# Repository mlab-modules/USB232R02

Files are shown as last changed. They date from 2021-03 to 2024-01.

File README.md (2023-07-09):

# USB232R02A
The module USB232R02A is a versatile and high-quality converter from USB to serial UART with 3.3V CMOS drive output and TTL input. It features a 5V-tolerant input and utilizes the reliable FT231XQ chip from FTDI The converter uses [FT231XQ](https://ftdichip.com/products/ft231xq/) chip from FTDI, ensuring maximum compatibility with all major operating systems. With supports for Full Speed USB and Full Handshake UART signals. 

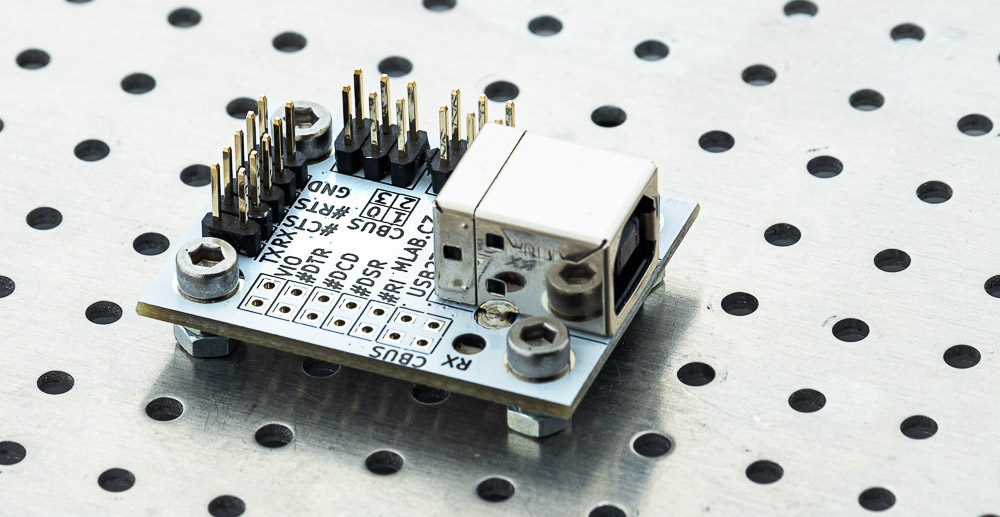
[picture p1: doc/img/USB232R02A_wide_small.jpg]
USB232R02A


The module provides the ability to power your devices via 5V from USB and 3.3V from the integrated power source simultaneously. The protection of the host device for overcurrent is realized by reversible fuse (750mA). 5V header is powerd from USB bus (trought fuse). The 3.3V power source is supplied from an LDO integrated in the FTDI converter. The 3.3V current limit is 50mA.

## What makes this module special?

USB23202A is differ from other USB-UART converters with its compatibility with MLAB standards, this fact will save any engineer or maker o lot of time. One of its key features is a unified dimension and pattern of M3 mounting screws that can be used to create a solid foundation and ground plane for your complex designs, thanks to its aluminum mounting board ALBASEx. This not only ensures mechanical durability but also makes it easy to mount your device into your final designs. With uniform cable wiring methods, this device protects your design from unnecessary malfunctions, providing you with a tool to easily and quickly prototype your high-quality devices. Invest in the USB23202A and take your designs to the next level!

## Parameters

| Parameter | Value | Description |
|---|---|---|
| Dimensions | 40,132 x 29,972 mm | PCB dimensions |
| IO | FT231XQ | Original FTDI | 
| Number of UART channels | 1 | Including all control signals | 
| USB speed | Full Speed (12 Mbps) | |
| USB connector | USB-B | USB 2.0 |
| Communication indication | 2x LED UART RX/TX | Purpose of LEDs can be changed |
| USB Class | FTDI driver | Virtual COM port |
| Power source | 5V and 3.3V (50mA) | 3.3V is provided by FT231XQ |

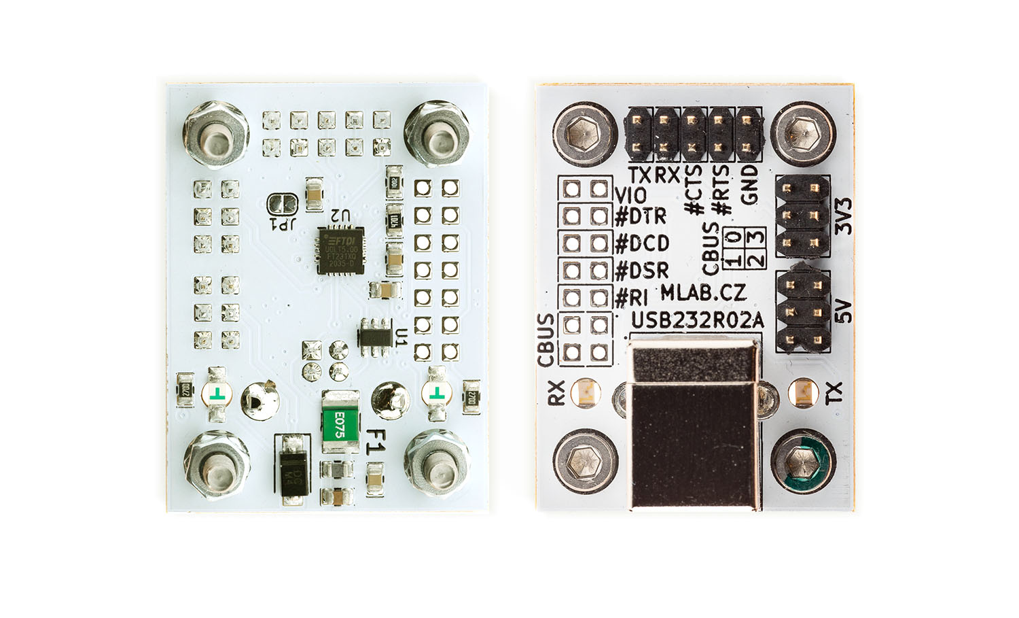
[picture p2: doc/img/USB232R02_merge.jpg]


## How to get this device? 

This device is sold by [Universal Scientific Technologies s.r.o.](https://www.ust.cz). If you are interested in our equipment, do not be afraid to [contact us](mailto:sale@ust.cz).

## Schematics

Schematics

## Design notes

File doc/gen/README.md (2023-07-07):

# PCB

Board size: 40.13x29.97 mm (1.58x1.18 inches)

- This is the size of the rectangle that contains the board
- Thickness: 1.6 mm (63 mils)
- Material: FR4
- Finish: None
- Layers: 2
- Copper thickness: 35 µm

Solder mask: TOP / BOTTOM

- Color: White

Silk screen: TOP / BOTTOM

- Color: Black

Stackup:

| Name | Type | Color | Thickness | Material | Epsilon_r | Loss tangent |
|---|---|---|---|---|---|---|
| F.SilkS | Top Silk Screen | Black | | | | |
| F.Paste | Top Solder Paste | | | | | |
| F.Mask | Top Solder Mask | White | 10 | | | |
| F.Cu | copper | | 35 | | | |
| dielectric 1 | core | | 1510 | FR4 | 4.5 | 0.020 |
| B.Cu | copper | | 35 | | | |
| B.Mask | Bottom Solder Mask | White | 10 | | | |
| B.Paste | Bottom Solder Paste  | | | | | |
| B.SilkS | Bottom Silk Screen | Black | | | | |

# Important sizes

Clearance: 0.2 mm (8 mils)

Track width: 0.2 mm (8 mils)

- By design rules: 0.2 mm (8 mils)

Drill: 0.5 mm (20 mils)

- Vias: 0.5 mm (20 mils) [Design: 0.4 mm (16 mils)]
- Pads: 1.0 mm (39 mils)
- The above values are real drill sizes, they add 0.1 mm (4 mils) to plated holes (PTH)

Via: 0.8/0.4 mm (31/16 mils)

- By design rules: 0.4/0.3 mm (16/12 mils)
- Micro via: yes [0.2/0.1 mm (8/4 mils)]
- Buried/blind via: yes
- Total: 35 (thru: 35 buried/blind: 0 micro: 0)

Outer Annular Ring: 0.15 mm (6 mils)

- By design rules: 0.26 mm (10 mils)

Eurocircuits class: 4B
- Using min drill 0.5 mm for an OAR of 0.15 mm

# General stats

Components count: (SMD/THT)

- Top: 0/9 (THT)
- Bottom: 18/0 (SMD)

Defined tracks:

Used tracks:

- 0.2 mm (8 mils) (2) defined: no
- 0.25 mm (10 mils) (152) defined: no
- 0.3 mm (12 mils) (5) defined: no
- 0.4 mm (16 mils) (41) defined: no
- 0.6 mm (24 mils) (19) defined: no

Defined vias:

Used vias:

- 0.8/0.4 mm (31/16 mils) (Count: 35, Aspect: 2.0 A) defined: no

Holes (excluding vias):

- 0.89 mm (35 mils) (36)
- 0.92 mm (36 mils) (4)
- 2.33 mm (92 mils) (2)
- 3.0 mm (118 mils) (4)

Oval holes:

Drill tools (including vias and computing adjusts and rounding):

- 0.5 mm (20 mils) (35)
- 1.0 mm (39 mils) (40)
- 2.45 mm (96 mils) (2)
- 3.1 mm (122 mils) (4)

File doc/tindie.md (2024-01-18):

#### What is it?

USB232R02 is a USB-UART adapter based on the FTDI chip [FT231XQ](https://ftdichip.com/products/ft231xq/).
The converter is characterized by its mechanical arrangement, which is compatible with the MLAB construction kit,
ensuring the robustness of manufactured devices and a unified approach to connecting individual components
using pin headers. The converter is equipped with a USB-B connector for connection to a computer, for example.
This ensures a high-quality USB connection without communication dropout. The converter supports
USB Full speed with a transfer rate of up to 12 Mbps.

USB232R02A_wide_small

The module contains a pair of output power connectors/pin headers with voltages of 5V and 3.3V.
The 5V supply is protected by a 750 mA fuse and is obtained from USB voltage. The 3.3V comes from an internal 
LDO with a maximum load of 50mA. The module is equipped with a pair of LEDs indicating RX/TX communication over USB.

The FTDI chip has a CMOS output (3.3V levels), and the pins are 5V compatible.
As a result, the module can be connected to both 3.3V and 5V constructions without configuration
changes and without the risk of damaging them.

The module includes all control pins (Handshake). Output signals are routed to pin headers with a standard 2.54mm pitch, and all pins are doubled. This way, you can easily create extensive constructions without dealing with complex connections or split connection cables.

The module has a wide range of uses. It can be used to connect various microcontrollers
to a computer for data capturing or for controlling them. It can also be used for configuring
or powering many existing devices that are often equipped with a serial interface at UART levels.
With the right cable, this converter can be used as a configuration interface for some networking devices,
for example.

You can find additional device parameters in the [README of the converter](https://github.com/mlab-modules/USB232R02#readme).

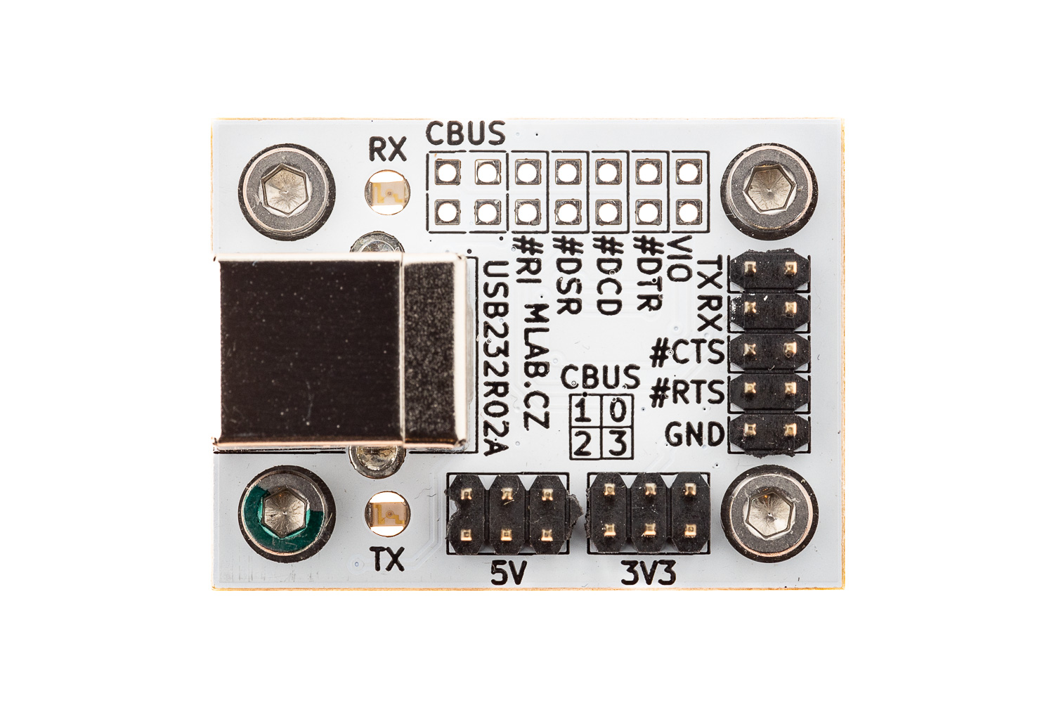
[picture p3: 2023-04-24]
doc/img/USB232R02_1.jpg

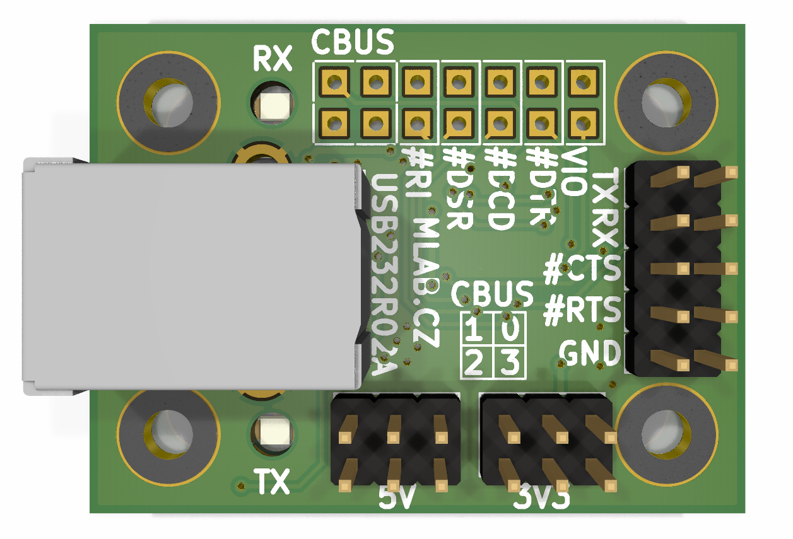
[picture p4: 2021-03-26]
doc/img/USB232R02A_top.png

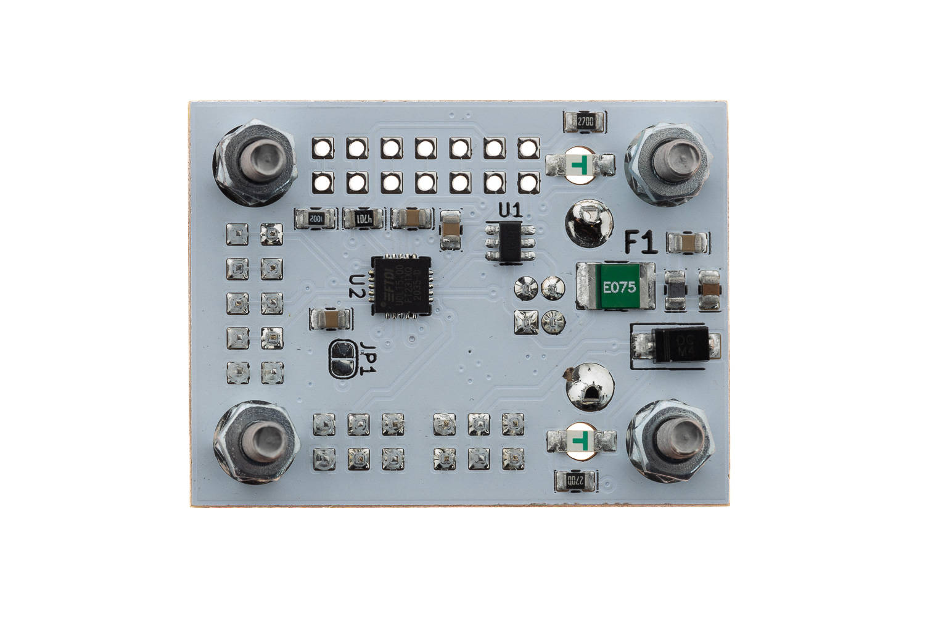
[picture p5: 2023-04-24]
doc/img/USB232R02_2.jpg

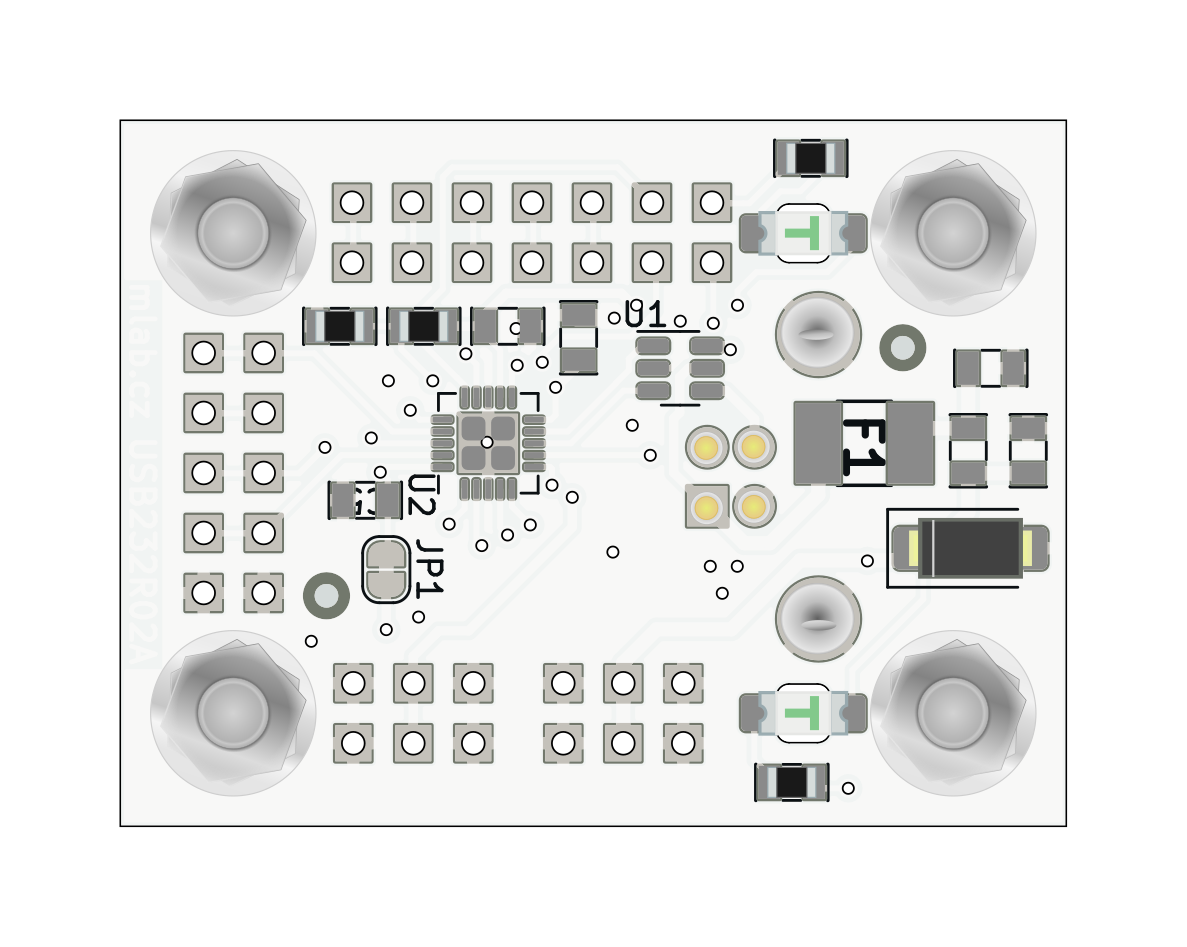
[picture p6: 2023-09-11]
doc/gen/img/USB232R02-bottom.png

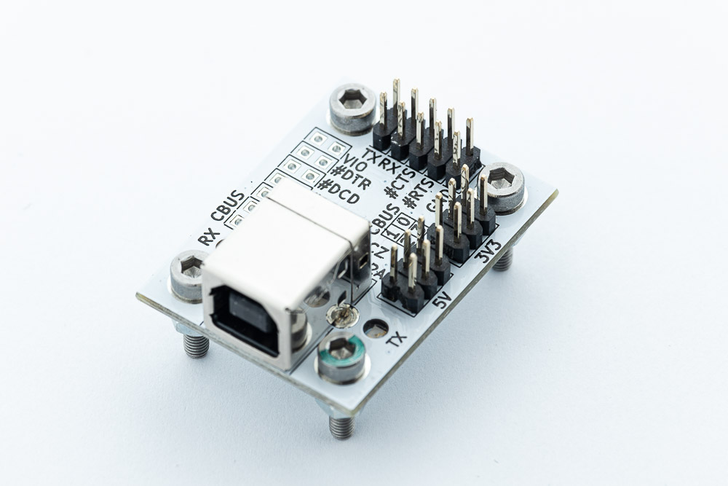
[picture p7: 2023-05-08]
doc/img/USB232R02A3.jpg

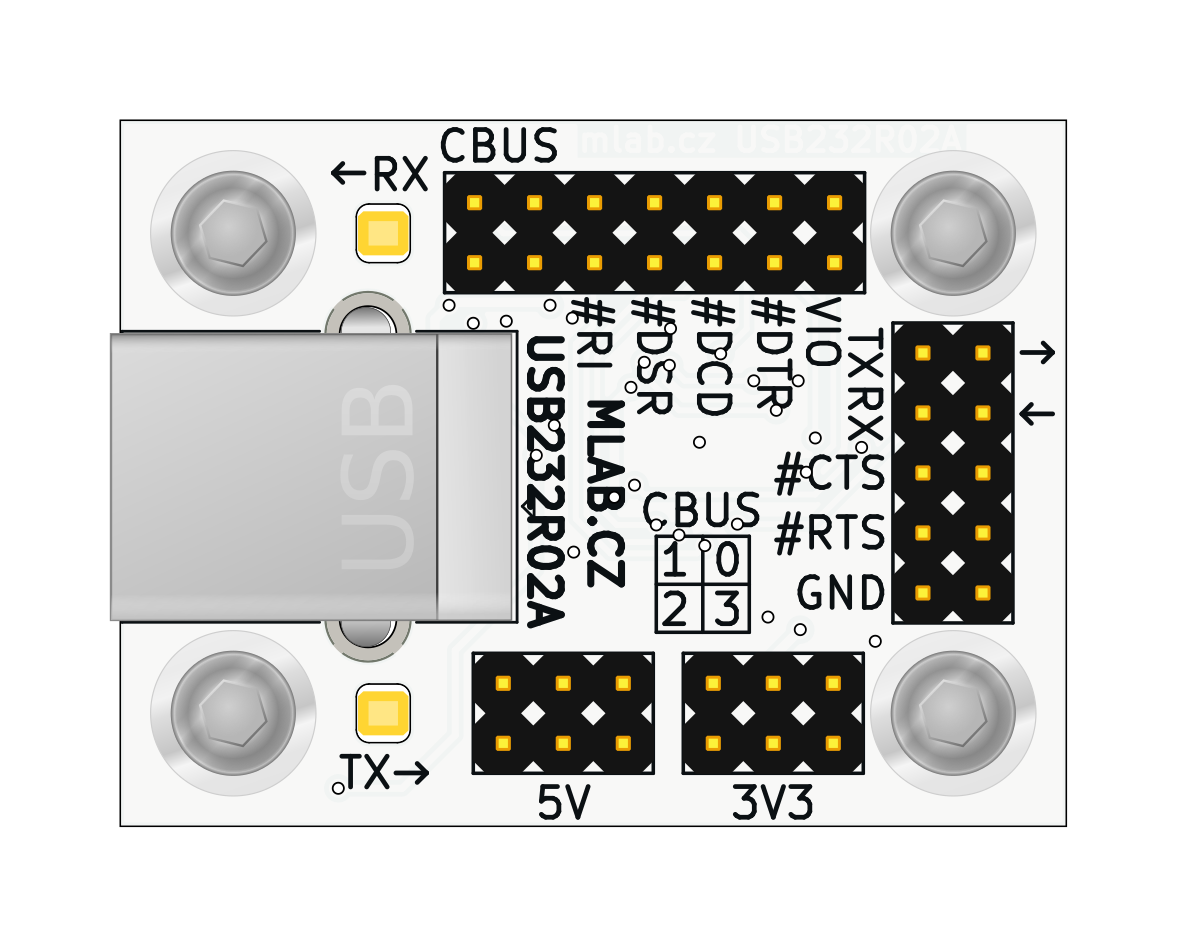
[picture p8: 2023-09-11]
doc/gen/img/USB232R02-top.png

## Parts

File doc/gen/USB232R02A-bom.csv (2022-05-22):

Row | Description | Part | References | Value | Footprint | Quantity Per PCB | Status | Datasheet | UST_ID
1 | Unpolarized capacitor | C | C1 | 10nF | SMD-0805 | 1 |  | ~ | 5c70984712875079b91f8b49
2 | Unpolarized capacitor | C | C3 C4 C5 | 100nF | SMD-0805 | 3 |  | ~ | 5c70984712875079b91f8b4c
3 | Unpolarized capacitor | C | C2 | 10uF | SMD-0805 | 1 |  | ~ | 5c70984812875079b91f8bbd
4 | Light emitting diode | LED | D3 | GREEN | LED_1206 | 1 |  | ~ | 5c70984412875079b91f8895
5 | Diode | D | D1 | M4 | D_SMA | 1 |  | ~ | 5c70984512875079b91f88ac
6 | Light emitting diode | LED | D2 | RED | LED_1206 | 1 |  | ~ | 5c70984412875079b91f8896
7 | Resettable fuse, polymeric positive temperature coefficient | Polyfuse | F1 | 750mA | 1812 | 1 |  | ~ | 5c70984512875079b91f88d2
8 | Ferrite bead, small symbol | FerriteBead_Small | FB1 | BLM21PG300SN1D | SMD-0805 | 1 |  | ~ | 5c70984412875079b91f87fd
9 | 2x01 2.54 mm pitch header, 2 pins next to each other are connected | HEADER_2x01_PARALLEL | J4 J9 J10 J11 J12 | - | Straight_2x01 | 5
10 | 1x01 2.54 mm pitch header | HEADER_1x01 | J13 J14 J15 J16 | - | Straight_1x01 | 4
11 | 2x01 2.54 mm pitch header, 2 pins next to each other are connected | HEADER_2x01_PARALLEL | J5 J6 J7 J8 J17 | HEADER_2x01_PARALLEL | Straight_2x01 | 5
12 | 2x03 2.54 mm pitch header, 2 pins next to each other are connected | HEADER_2x03_PARALLEL | J2 J3 | HEADER_2x03_PARALLEL | Straight_2x03 | 2
13 | USB Type B connector | USB_B | J1 | USB_B | USB_B_OST_USB-B1HSxx_Horizontal | 1 |  | ~ | 5c70984412875079b91f87a8
14 | Resistor | R | R3 R4 | 270R | SMD-0805 | 2 |  | ~ | 5c70984512875079b91f8983
15 | Resistor | R | R1 | 4k7 | SMD-0805 | 1 |  | ~ | 5c70984612875079b91f8995
16 | Resistor | R | R2 | 10k | SMD-0805 | 1 |  | ~ | 5c70984612875079b91f899f
17 | Full Speed USB to Full Handshake UART, QFN-20 | FT231XQ | U2 | FT231XQ | QFN-20-1EP_4x4mm_P0.5mm_EP2.5x2.5mm | 1 |  | https://www.ftdichip.com/Support/Documents/DataSheets/ICs/DS_FT231X.pdf | 605d7fe0128750769e769adb
18 | Very low capacitance ESD protection diode, 2 data-line, SOT-23-6 | USBLC6-2SC6 | U1 | USBLC6-2SC6 | SOT-23-6 | 1 |  | https://www.st.com/resource/en/datasheet/usblc6-2.pdf | 5e82e0691287502a334a778c
Project info:
Schematic: | USB232R02A
Variant: | default
Revision:
Date: | 2021-03-25
KiCad Version: | 6.0.4-6f826c9f35~116~ubuntu20.04.1
Statistics:
Component Groups: | 18
Component Count: | 33
Fitted Components: | 33
Number of PCBs: | 1
Total Components: | 33

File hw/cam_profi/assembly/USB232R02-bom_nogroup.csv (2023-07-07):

Component | Description | Part | References | Value | Footprint | Quantity Per PCB | Datasheet | lcsc | ust_id
1 | Unpolarized capacitor | C | C1 | 10nF | SMD-0805 | 1 | ~ | C472806 | 5c70984712875079b91f8b49
2 | Unpolarized capacitor | C | C3C4C5 | 100nF | SMD-0805 | 3 | ~ | C111492 | 5c70984712875079b91f8b4c
3 | Unpolarized capacitor | C | C2 | 10uF | SMD-0805 | 1 | ~ | C17024 | 5c70984812875079b91f8bbd
4 | Light emitting diode | LED | D3 | GREEN | LED_1206_2 | 1 | https://www.tme.eu/Document/283cf8402cc8d70fa16840405395cb5a/kptr-3216cgck.pdf | C598394 | 5c70984412875079b91f8895
5 | Diode | D | D1 | M4 | D_SMA | 1 | ~ | C466506 | 5c70984512875079b91f88ac
6 | Light emitting diode | LED | D2 | RED | LED_1206_2 | 1 | http://www.kingbright.com/attachments/file/psearch/000/00/20160808bak/KPTR-3216SURCK(Ver.15A).pdf | C598398 | 5c70984412875079b91f8896
7 | Resettable fuse, polymeric positive temperature coefficient | Polyfuse | F1 | 750mA | 1812 | 1 | ~ | C269130 | 5c70984512875079b91f88d2
8 | Ferrite bead, small symbol | FerriteBead_Small | FB1 | BLM21PG300SN1D | SMD-0805 | 1 | ~ | C16903 | 5c70984412875079b91f87fd
9 | 2x03 2.54 mm pitch header, 2 pins next to each other are connected | HEADER_2x03_PARALLEL | J2J3 | HEADER_2x03 | Straight_2x03 | 2 |  | C706893
10 | 2x05 2.54 mm pitch header, 2 pins next to each other are connected | HEADER_2x05_PARALLEL | J19 | HEADER_2x05 | Straight_2x05 | 1 |  | C706895
11 | 2x07 2.54 mm pitch header | HEADER_2x07 | J18 | HEADER_2x07 | Straight_2x07 | 1 |  | C706897
12 | USB Type B connector | USB_B | J1 | USB_B | USB_B_OST_USB-B1HSxx_Horizontal | 1 | ~ | C490687 | 5c70984412875079b91f87a8
13 | Resistor | R | R3R4 | 270R | SMD-0805 | 2 | ~ | C228675 | 5c70984512875079b91f8983
14 | Resistor | R | R1 | 4k7 | SMD-0805 | 1 | ~ | C60816 | 5c70984612875079b91f8995
15 | Resistor | R | R2 | 10k | SMD-0805 | 1 | ~ | C84376 | 5c70984612875079b91f899f
16 | Full Speed USB to Full Handshake UART, QFN-20 | FT231XQ | U2 | FT231XQ | QFN-20-1EP_4x4mm_P0.5mm_EP2.5x2.5mm | 1 | https://www.ftdichip.com/Support/Documents/DataSheets/ICs/DS_FT231X.pdf | C132159 | 605d7fe0128750769e769adb
17 | Very low capacitance ESD protection diode, 2 data-line, SOT-23-6 | USBLC6-2SC6 | U1 | USBLC6-2SC6 | SOT-23-6 | 1 | https://www.st.com/resource/en/datasheet/usblc6-2.pdf | C7519 | 5e82e0691287502a334a778c

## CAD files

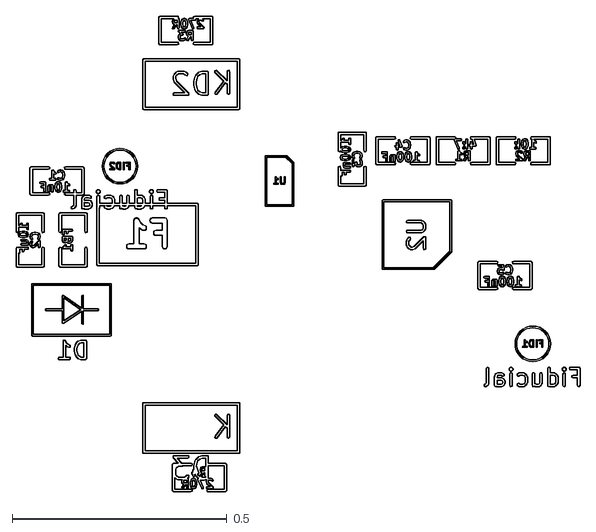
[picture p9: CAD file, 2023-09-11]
doc/gen/dxf/USB232R02-B_Fab.dxf
1.31 x 1.11

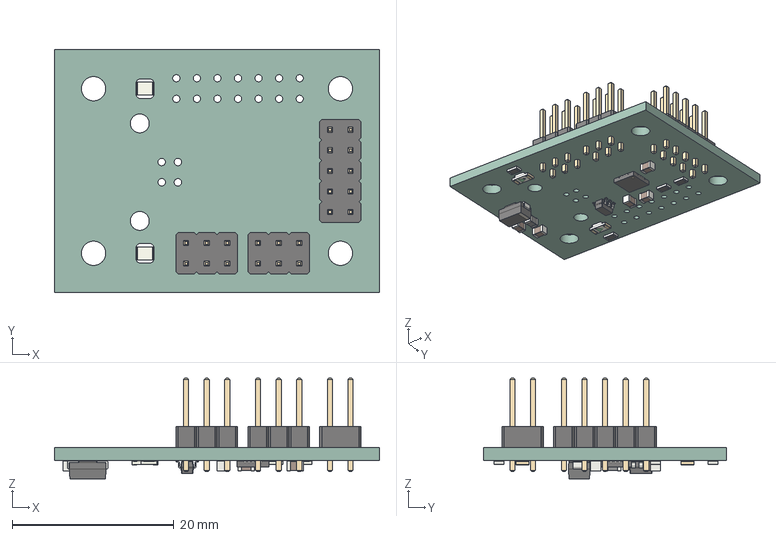
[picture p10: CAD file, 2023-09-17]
doc/gen/USB232R02.step
40.1 x 30.0 x 12.4 mm
tmpykgqynk8 PCB

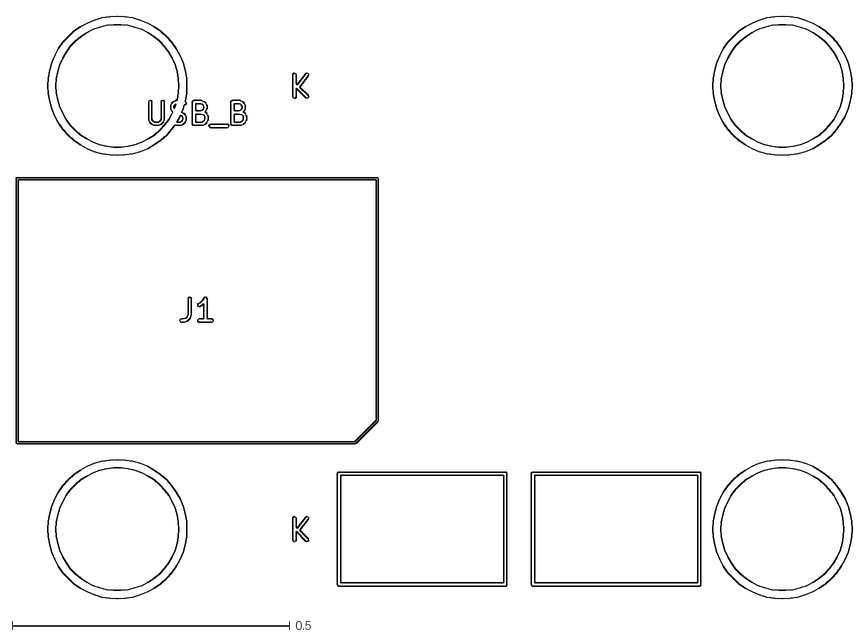
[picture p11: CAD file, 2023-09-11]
doc/gen/dxf/USB232R02-F_Fab.dxf
1.51 x 1.05

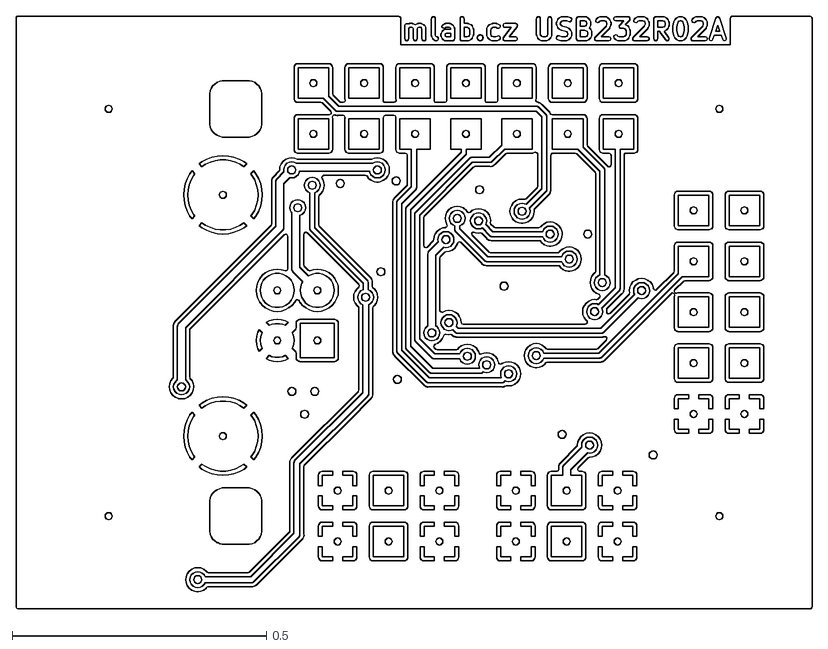
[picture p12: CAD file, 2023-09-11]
doc/gen/dxf/USB232R02-F_Cu.dxf
1.56 x 1.16

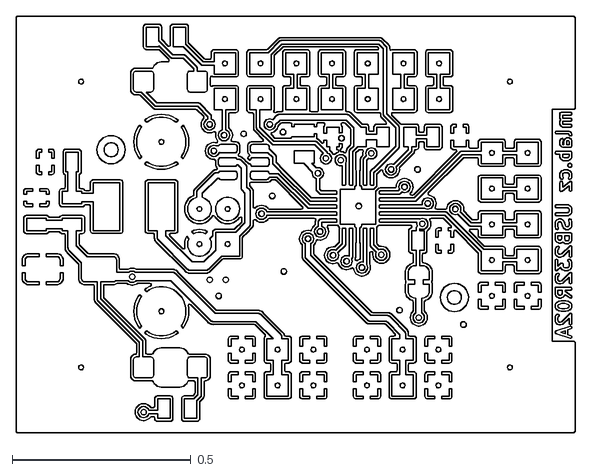
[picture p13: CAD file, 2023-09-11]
doc/gen/dxf/USB232R02-B_Cu.dxf
1.56 x 1.16

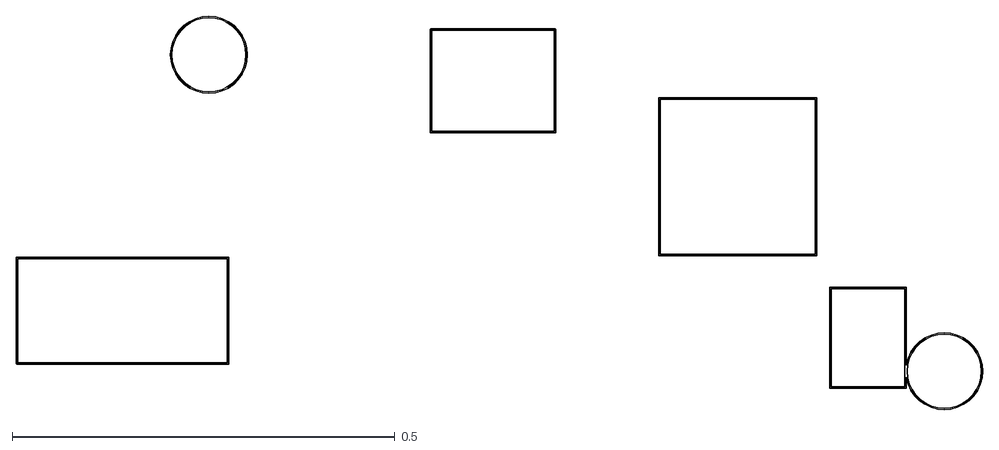
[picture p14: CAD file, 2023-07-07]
doc/gen/dxf/USB232R02-B_Courtyard.dxf
1.26 x 0.514

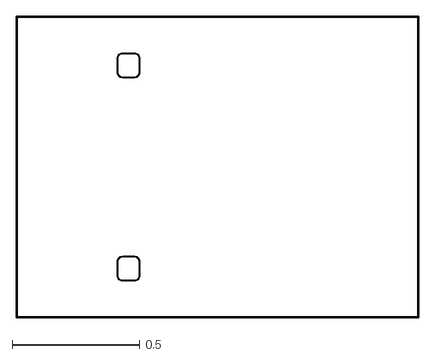
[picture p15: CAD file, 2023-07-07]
doc/gen/dxf/USB232R02-Edge_Cuts.dxf
1.58 x 1.18

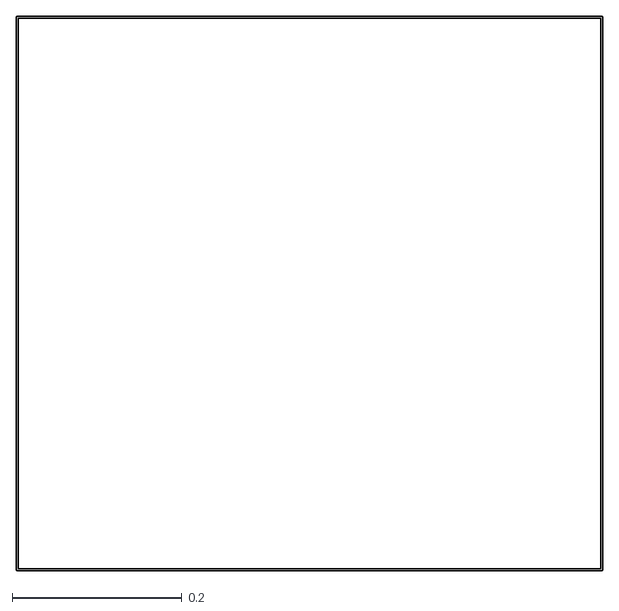
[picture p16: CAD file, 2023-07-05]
doc/gen/dxf/USB232R02-F_Courtyard.dxf
0.691 x 0.653

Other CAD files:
doc/gen/dxf/USB232R02-Uivatel_9.dxf
doc/gen/dxf/USB232R02-Uivatel_8.dxf
doc/gen/dxf/USB232R02-User_Drawings.dxf
doc/gen/dxf/USB232R02A-Uivatel_5.dxf
doc/gen/dxf/USB232R02A-Uivatel_3.dxf
doc/gen/dxf/USB232R02-Uivatel_1.dxf
doc/gen/dxf/USB232R02A-User_Drawings.dxf
doc/gen/dxf/USB232R02A-Uivatel_2.dxf
doc/gen/dxf/USB232R02-Uivatel_5.dxf
doc/gen/dxf/USB232R02-User_Eco2.dxf
doc/gen/dxf/USB232R02-B_Adhesive.dxf
doc/gen/dxf/USB232R02-B_Mask.dxf
doc/gen/dxf/USB232R02-B_Paste.dxf
doc/gen/dxf/USB232R02-B_Silkscreen.dxf
doc/gen/dxf/USB232R02-F_Adhesive.dxf
doc/gen/dxf/USB232R02-F_Mask.dxf
doc/gen/dxf/USB232R02-F_Paste.dxf
doc/gen/dxf/USB232R02-F_Silkscreen.dxf
doc/gen/dxf/USB232R02-Margin.dxf
doc/gen/dxf/USB232R02-Uivatel_2.dxf
doc/gen/dxf/USB232R02-Uivatel_3.dxf
doc/gen/dxf/USB232R02-Uivatel_4.dxf
doc/gen/dxf/USB232R02-Uivatel_6.dxf
doc/gen/dxf/USB232R02-Uivatel_7.dxf
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

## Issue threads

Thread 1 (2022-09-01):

USB signals needs to be routed differentially

kaklik, 2022-09-01:
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

Vbus should be routed in the opposite direction from pin 5 of U1. Then D- and D+ could be routed parallel with the same length.  Similar constraints apply to DM and DP signals.

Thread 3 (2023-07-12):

Missing power LED

roman-dvorak, 2023-07-12:
Na modulu není LEDka indikující přítomnost napájení. Vzhledem k tomu, že tento modul často slouží jako zdroj napájení, tak by bylo užitečné, aby takovou indikaci obsahoval.

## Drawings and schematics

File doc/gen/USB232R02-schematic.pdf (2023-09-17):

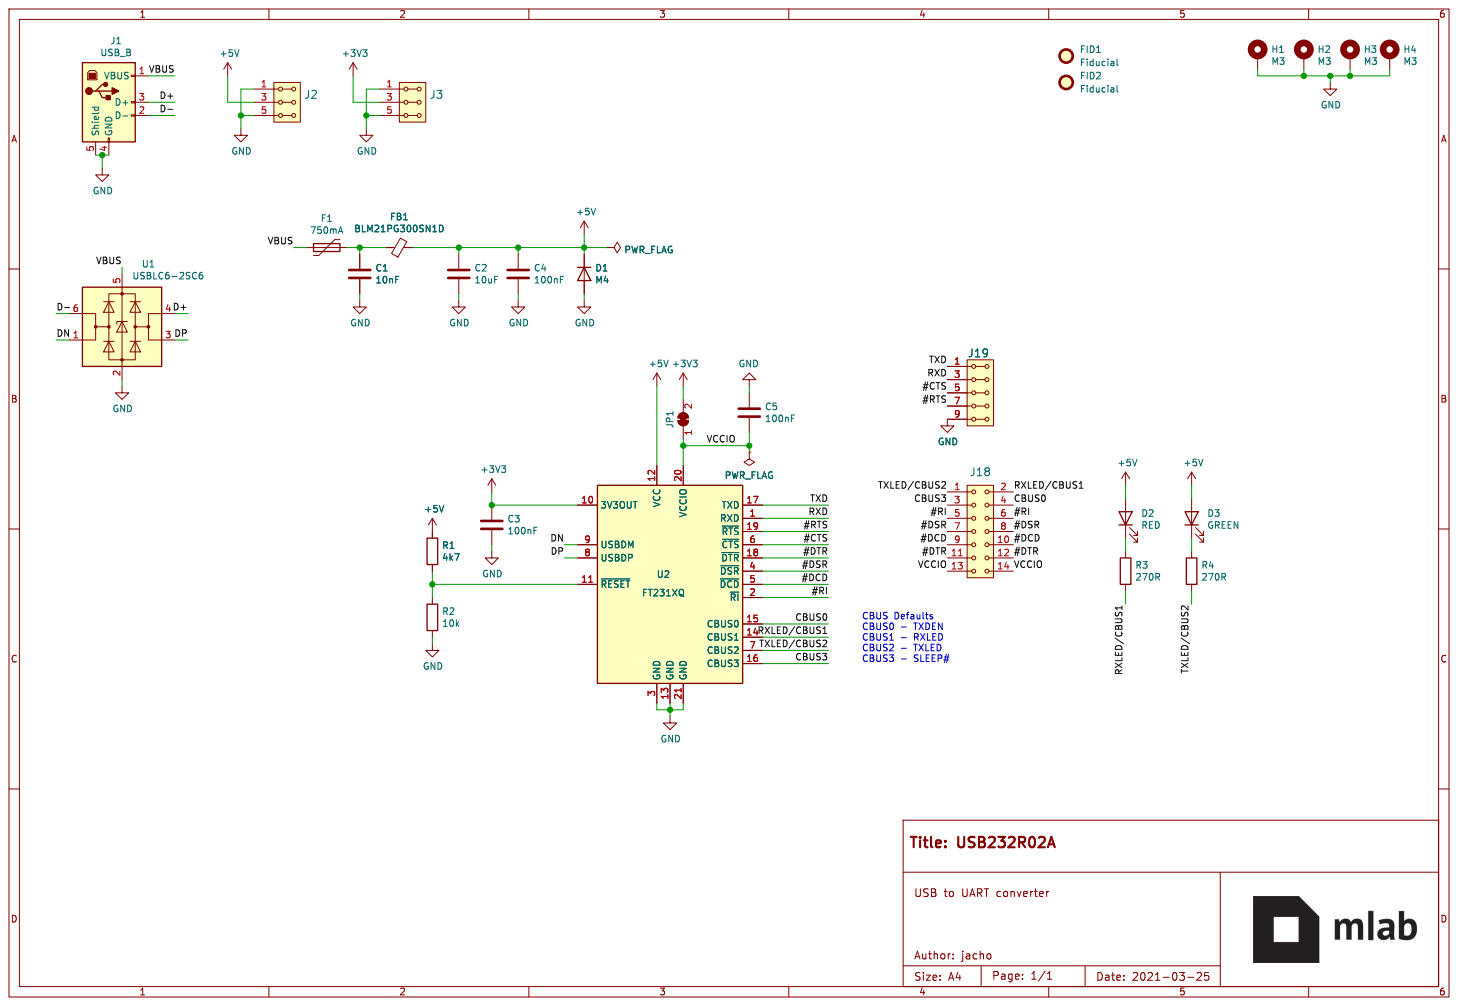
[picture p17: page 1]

3 ~{DSR}4 ~{DCD}5 ~{CTS}6 CBUS2 7 USBDP 8 USBDM 9 FB1 BLM21PG300SN1D

3 ~{DSR}4 ~{DCD}5 ~{CTS}6 CBUS2 7 USBDP 8 USBDM 9 U2 FT231XQ

USB to UART converter

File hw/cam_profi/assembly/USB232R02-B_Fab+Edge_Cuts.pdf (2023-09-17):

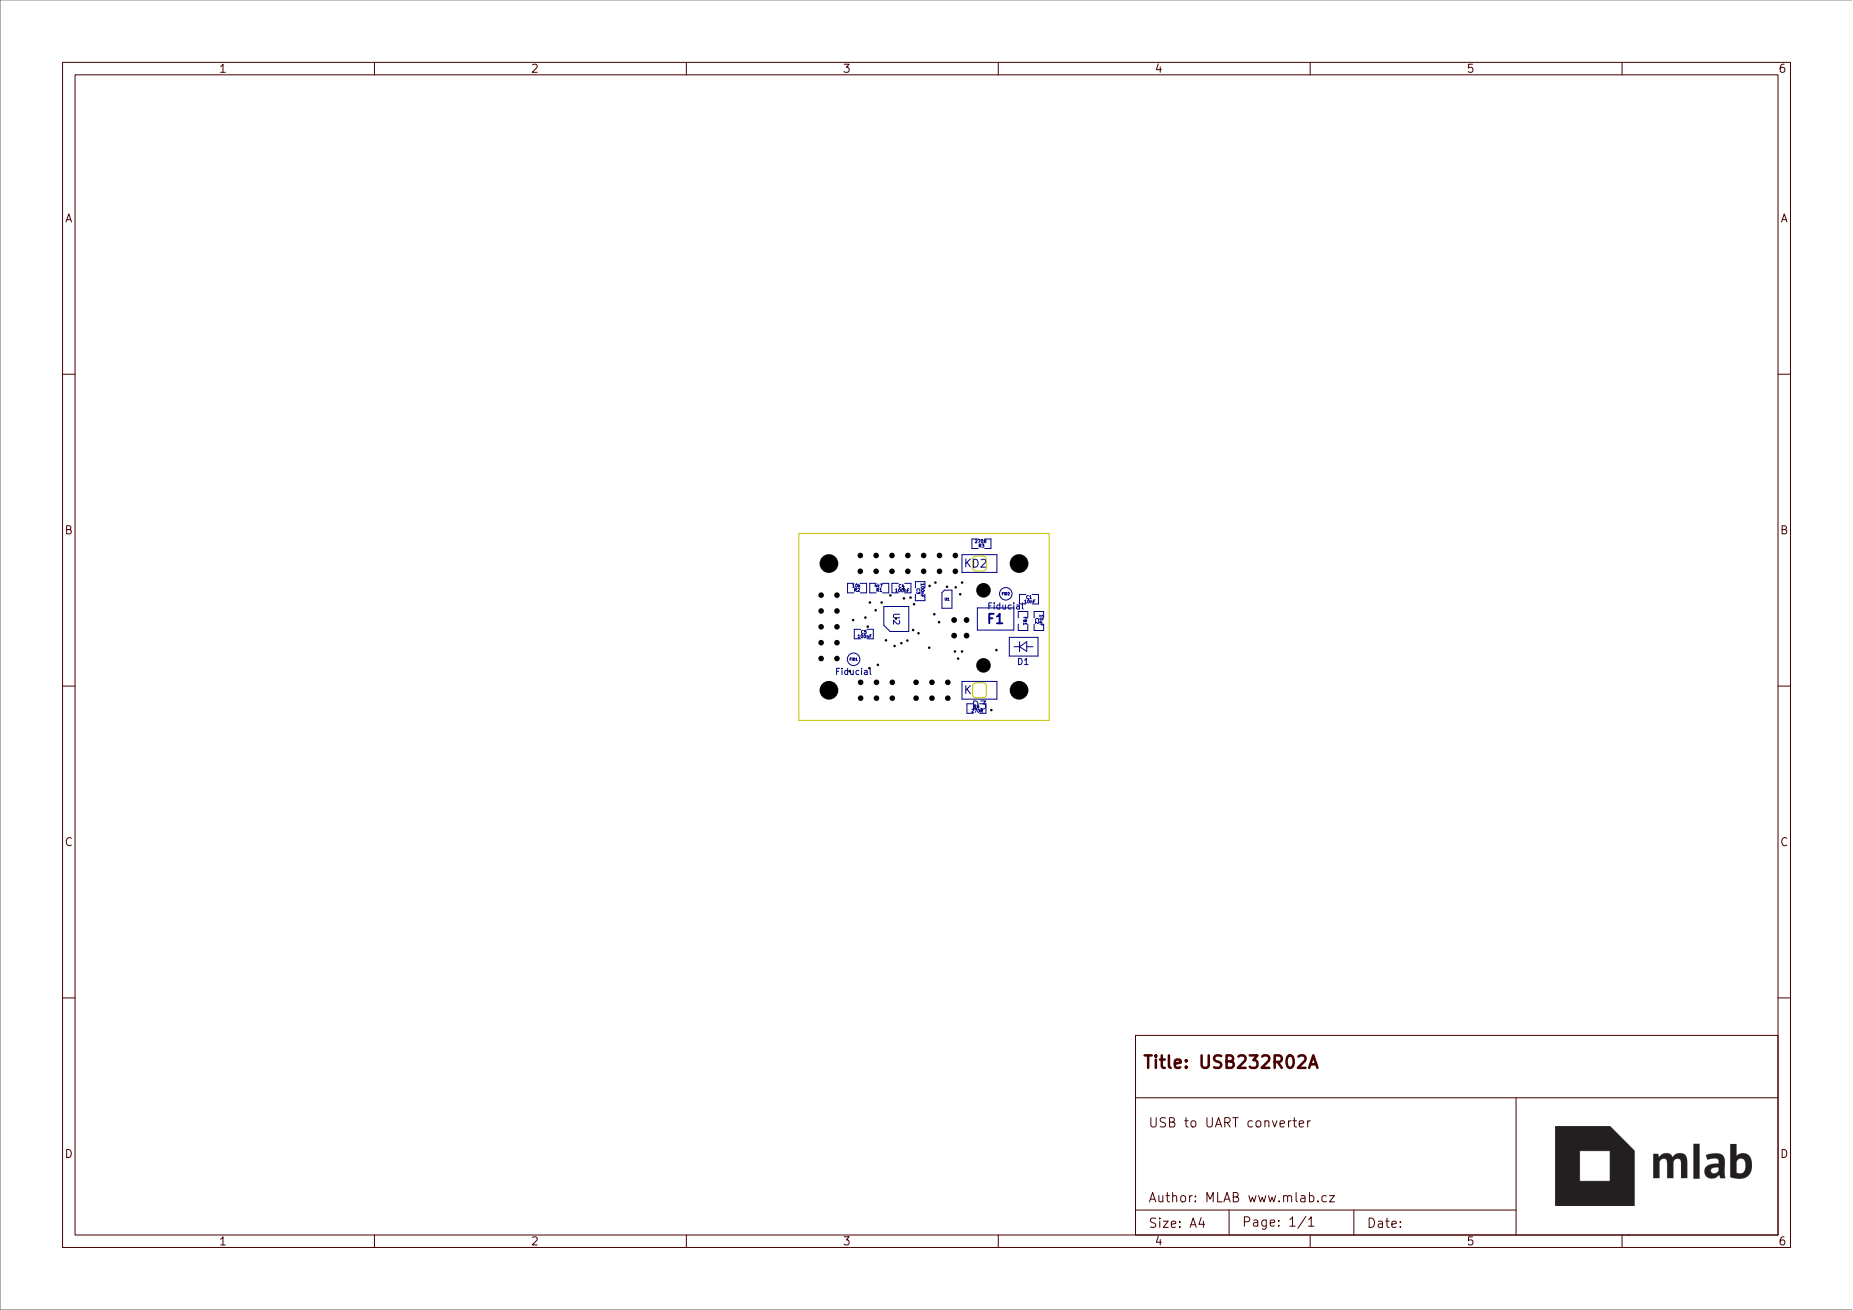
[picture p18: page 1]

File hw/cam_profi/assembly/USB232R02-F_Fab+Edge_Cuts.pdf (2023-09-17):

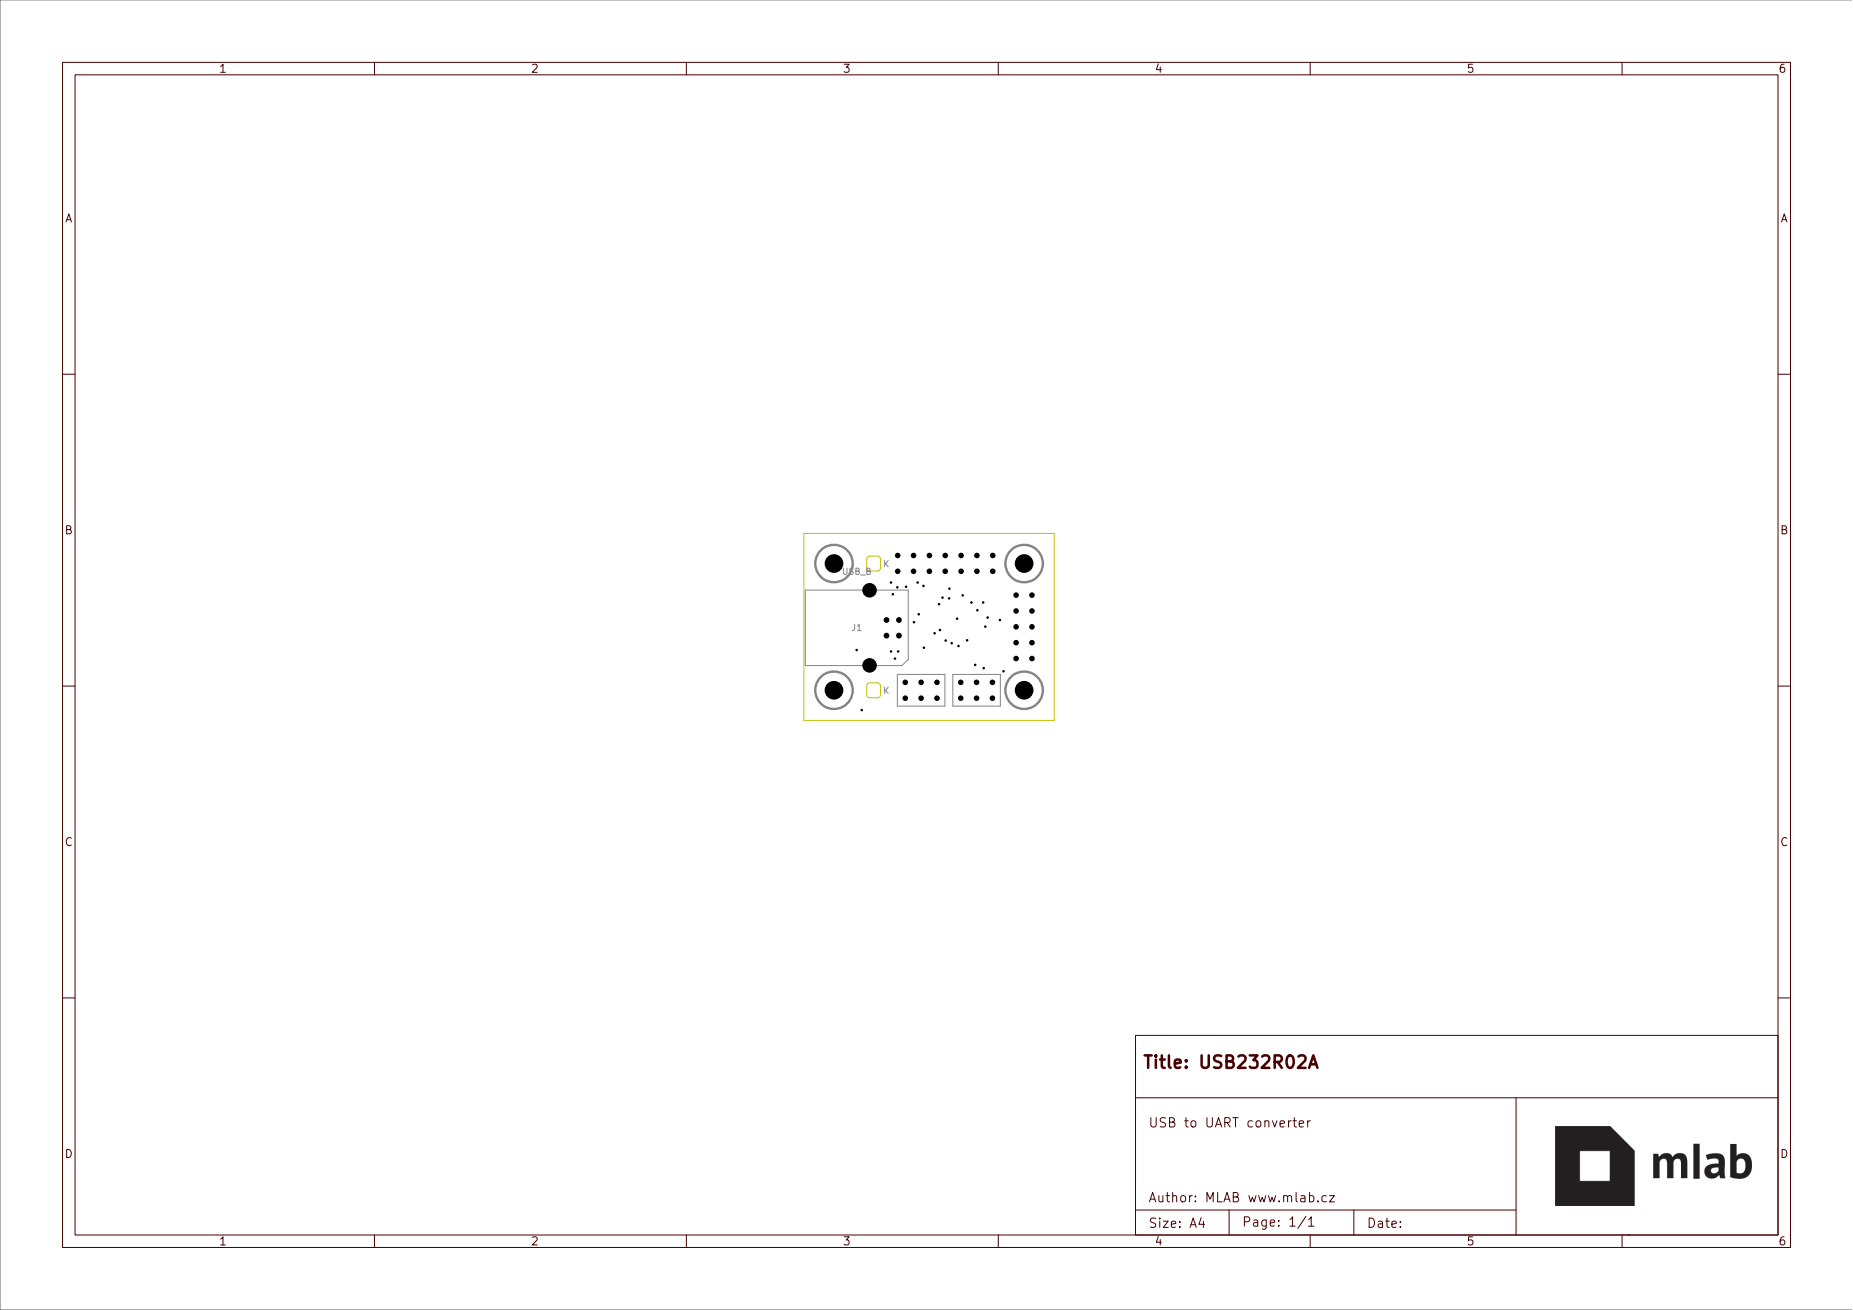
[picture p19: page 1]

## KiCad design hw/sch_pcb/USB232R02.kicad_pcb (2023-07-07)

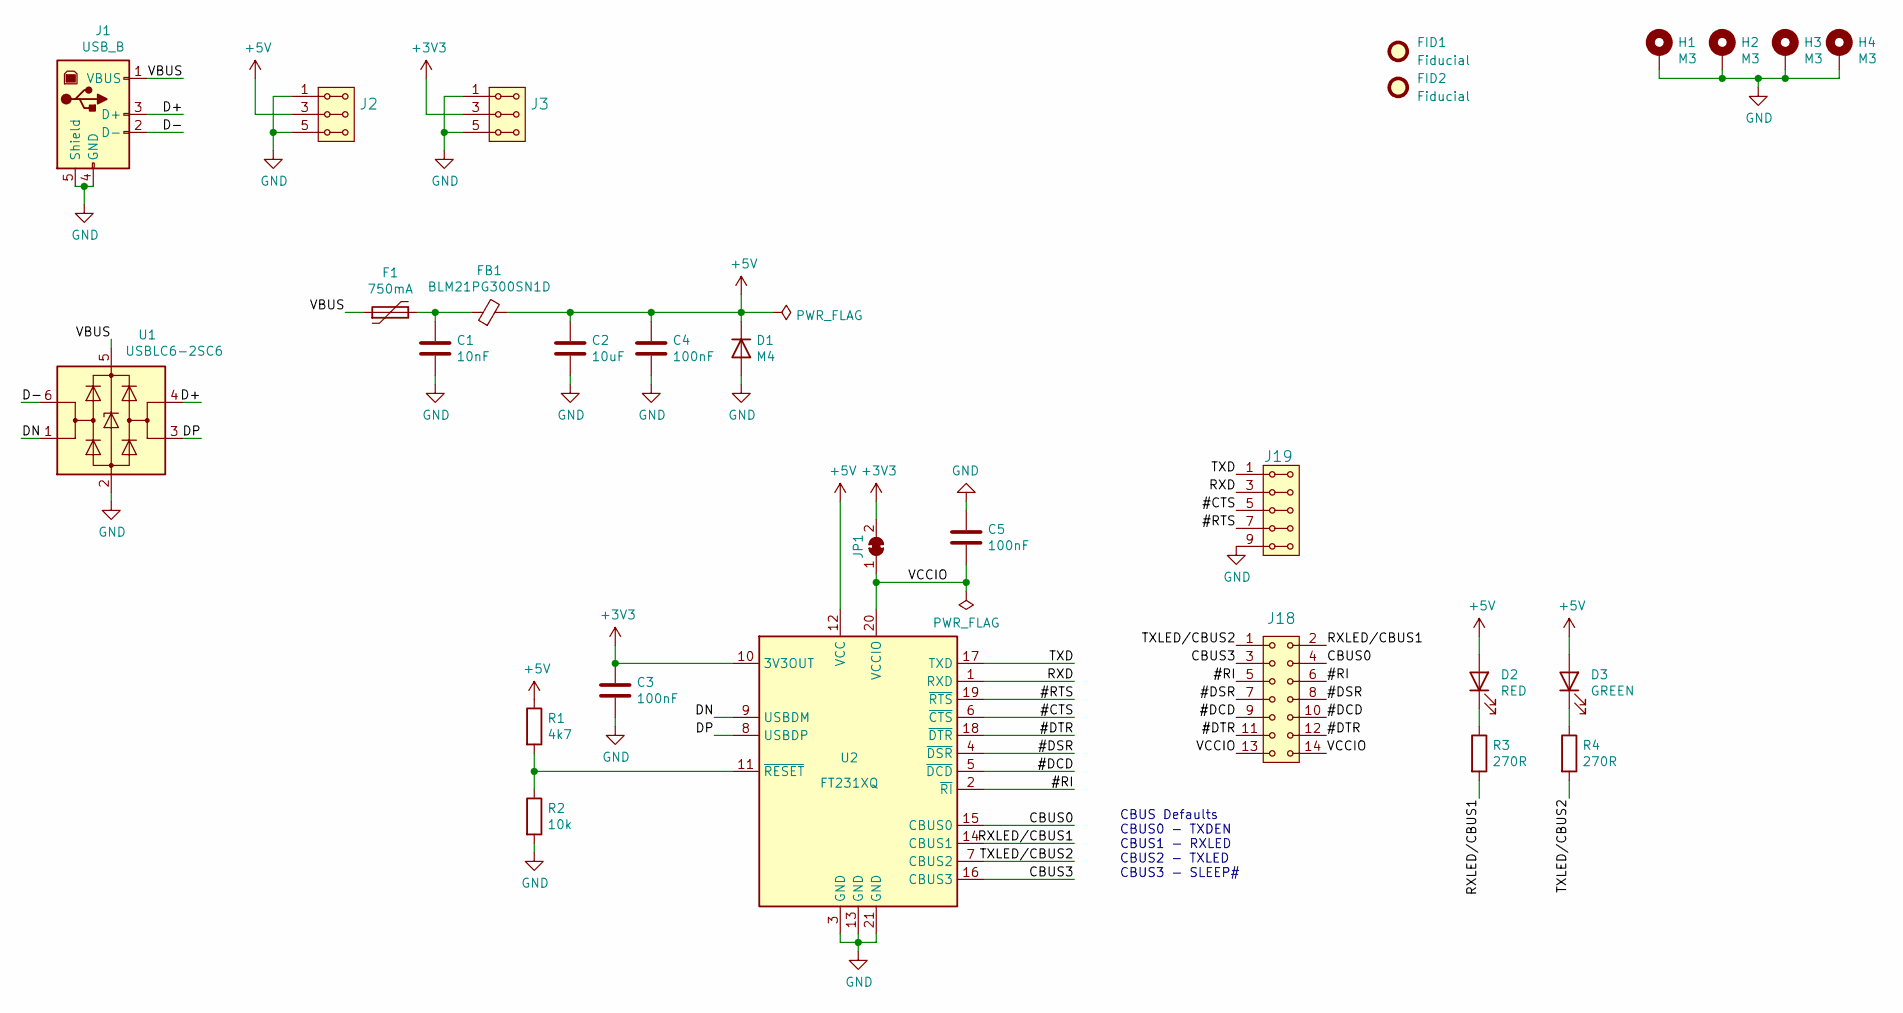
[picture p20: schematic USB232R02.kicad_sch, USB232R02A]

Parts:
C1: 10nF; SMD-0805; LCSC C913645
C2: 10uF; SMD-0805; LCSC C17024
C3, C4, C5: 100nF; SMD-0805; LCSC C111492
D1: M4; D_SMA; LCSC C466506
D2: RED; LED_1206_2; LCSC C598398
D3: GREEN; LED_1206_2; LCSC C598394
F1: 750mA; 1812; LCSC C269130
FB1: BLM21PG300SN1D; SMD-0805; LCSC C16903
FID1, FID2: Fiducial; Fiducial_1mm_Mask2mm
H1, H2, H3, H4: M3; MountingHole_3mm
J1: USB_B; USB_B_OST_USB-B1HSxx_Horizontal; LCSC C490687
J2, J3: HEADER_2x03; Straight_2x03; LCSC C706893
J18: HEADER_2x07; Straight_2x07; LCSC C706897
J19: HEADER_2x05; Straight_2x05; LCSC C706895
JP1: SolderJumper_2_Bridged; SolderJumper-2_P1.3mm_Bridged_RoundedPad1.0x1.5mm
R1: 4k7; SMD-0805; LCSC C60816
R2: 10k; SMD-0805; LCSC C84376
R3, R4: 270R; SMD-0805; LCSC C228675
U1: USBLC6-2SC6; SOT-23-6; LCSC C7519
U2: FT231XQ; QFN-20-1EP_4x4mm_P0.5mm_EP2.5x2.5mm; LCSC C132159

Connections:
+3V3: C3.1, J3.3, J3.4, JP1.2 (B), U2.10 (3V3OUT)
+5V: C2.1, C4.1, D1.1 (K), D2.2 (A), D3.2 (A), FB1.2, J2.3, J2.4, R1.1, U2.12 (VCC)
/#CTS: J19.5, J19.6, U2.6 (~CTS)
/#DCD: J18.9, J18.10, U2.5 (~DCD)
/#DSR: J18.7, J18.8, U2.4 (~DSR)
/#DTR: J18.11, J18.12, U2.18 (~DTR)
/#RI: J18.5, J18.6, U2.2 (~RI)
/#RTS: J19.7, J19.8, U2.19 (~RTS)
/CBUS0: J18.4, U2.15 (CBUS0)
/CBUS3: J18.3, U2.16 (CBUS3)
/D+: J1.3 (D+), U1.4 (I/O2)
/D-: J1.2 (D-), U1.6 (I/O1)
/DN: U1.1 (I/O1), U2.9 (USBDM)
/DP: U1.3 (I/O2), U2.8 (USBDP)
/RXD: J19.3, J19.4, U2.1 (RXD)
/RXLED/CBUS1: J18.2, R3.2, U2.14 (CBUS1)
/TXD: J19.1, J19.2, U2.17 (TXD)
/TXLED/CBUS2: J18.1, R4.2, U2.7 (CBUS2)
/VBUS: F1.1, J1.1 (VBUS), U1.5 (VBUS)
/VCCIO: C5.2, J18.13, J18.14, JP1.1 (A), U2.20 (VCCIO)
GND: C1.2, C2.2, C3.2, C4.2, C5.1, D1.2 (A), H1.1, H2.1, H3.1, H4.1, J1.4 (GND), J1.5 (Shield), J2.1, J2.2, J2.5, J2.6, J3.1, J3.2, J3.5, J3.6, J19.9, J19.10, R2.2, U1.2 (GND), U2.3 (GND), U2.13 (GND), U2.21 (GND)
unnamed: C1.1, F1.2, FB1.1
unnamed: D2.1 (K), R3.1
unnamed: D3.1 (K), R4.1
unnamed: R1.2, R2.1, U2.11 (~RESET)

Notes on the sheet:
CBUS Defaults CBUS0 - TXDEN CBUS1 - RXLED CBUS2 - TXLED CBUS3 - SLEEP#

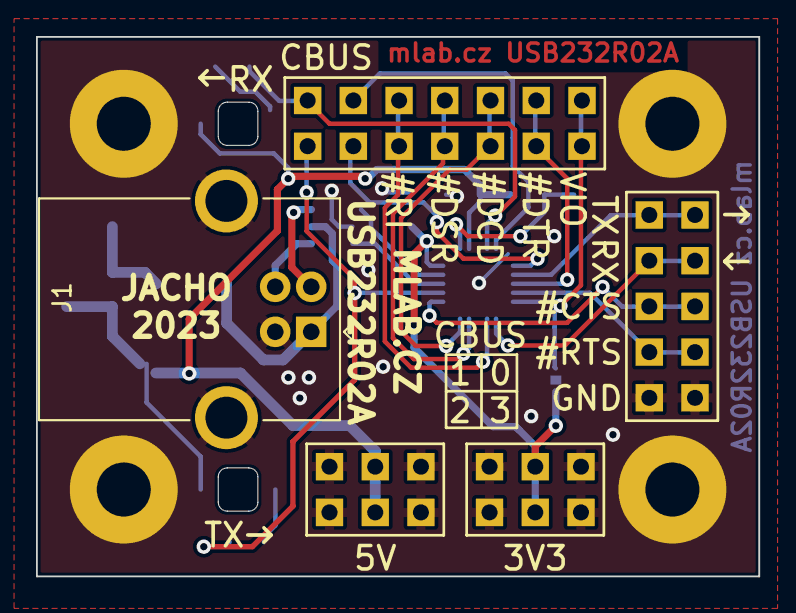
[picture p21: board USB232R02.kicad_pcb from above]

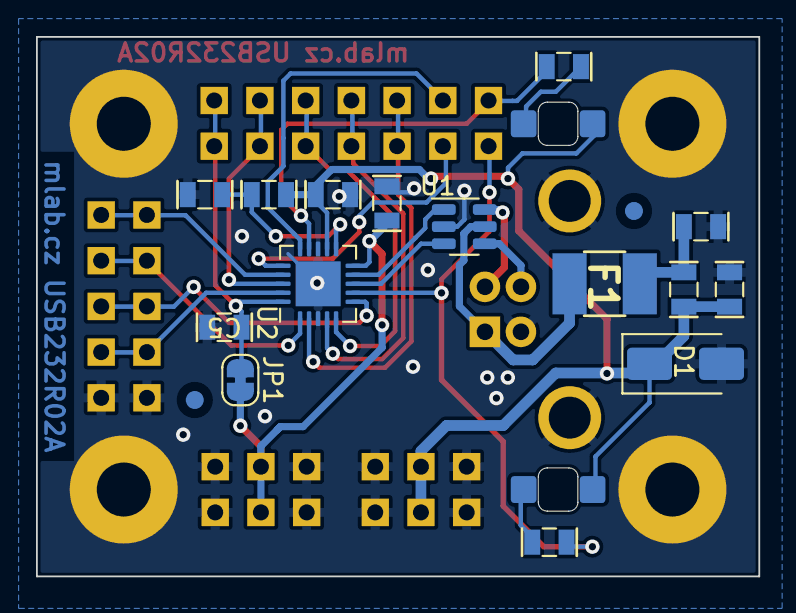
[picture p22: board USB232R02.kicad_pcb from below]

Board: 2 copper layers, 40.1 x 30.0 mm, 28 parts (19 on the bottom side), 25 nets.

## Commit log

2020-12-02 Oprava složkové struktury.
    [USB232R02A.kicad_pcb, USB232R02A.kicad_sch]
2021-03-25 Add MLAB title block. Minor layout cleanup Cleanup silkscreen.
    [USB232R02A.kicad_pcb, USB232R02A.kicad_sch]
2022-04-06 Update actions products
    [USB232R02A-B_Cu.gbr, USB232R02A-B_Mask.gbr, USB232R02A-B_Paste.gbr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]
2022-05-21 Edit PCB
    [USB232R02A.kicad_pcb]
2022-05-22 vyreseni DRC, uprava sablon
    [USB232R02A.kicad_pcb, USB232R02A.kicad_sch]
2022-05-22 Úprava potisku
    [USB232R02A.kicad_pcb]
2022-06-14 Update title block and resolve ERC issues.
    [USB232R02A.kicad_sch]
2022-09-23 Swap mounting holes from top to bottom, to allow its use for aligment in PnP data output.
    [USB232R02A.kicad_pcb]
2022-09-27 unucessfull attempt to set board panel
2022-09-27 new attempt to set PCB panel.
2022-10-03 Update job file according real position of board.
2022-10-03 Set Z coordinate of board.
2023-02-09 Kibot update (#2)
    * Update kicad_outputs.yml
    * Update actions products
    * submodule update
    * Update kicad_outputs.yml
    * Update actions products
    * Update kicad_outputs.yml
    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
    [USB232R02-B_Adhesive.dxf, USB232R02-B_Courtyard.dxf, USB232R02-B_Cu.dxf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]
2023-04-25 Test of different setups of PCB panel. Prior introducing the panel fiducials.
2023-06-14 update submodule
    [USB232R02.kicad_pcb]
2023-07-07 clean repo, update kicad footprints, prepare to assembly
    [USB232R02.kicad_pcb, USB232R02.kicad_sch]
2023-07-07 aktualizace kodu a konfigurace
    [USB232R02.kicad_sch]
2023-09-07 add pnp related files
    [USB232R02A_cpl.csv]
